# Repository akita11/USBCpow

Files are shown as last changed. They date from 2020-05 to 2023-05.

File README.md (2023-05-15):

# USBCpow

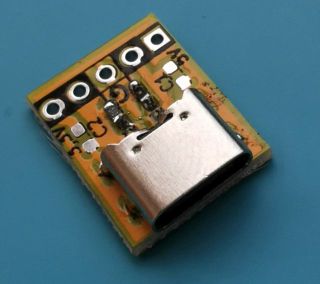
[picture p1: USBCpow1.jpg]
5V


USB Type-Cから5Vを供給するボードです。オプションで3.3Vレギュレータを載せて、3.3Vも出力することができます。

なお実際に供給できる電流は、給電側（USB ACアダプタやモバイルバッテリ）の性能に依存します。また3.3V出力は600mAまでです。

完成品はスイッチサイエンス等で委託販売中です。[5V版](https://www.switch-science.com/products/6434) / [5V/3.3V版](https://www.switch-science.com/products/6435)

# 使い方

+5V（および+3.3V）、GNDの端子にビニール線やピンヘッダやソケットをとりつけ、回路に電源を供給します。

以下のようにGNDと+5V（または+3.3V）に2ピンのピンヘッダをとりつけることで、ブレッドボードの電源ラインへの給電につかうことができます。

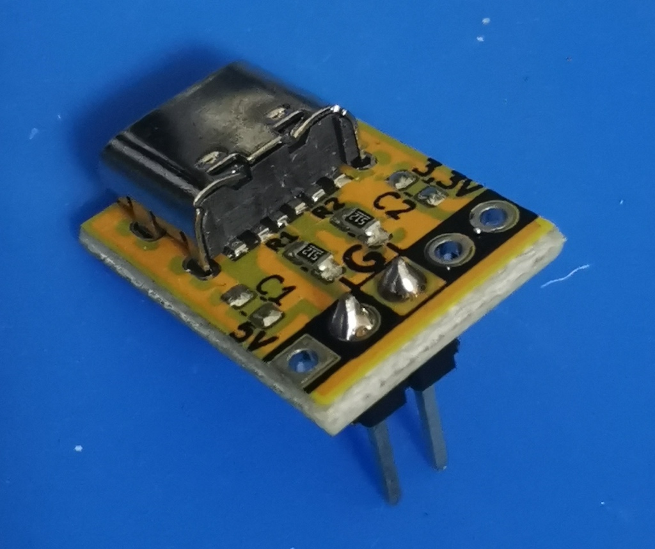
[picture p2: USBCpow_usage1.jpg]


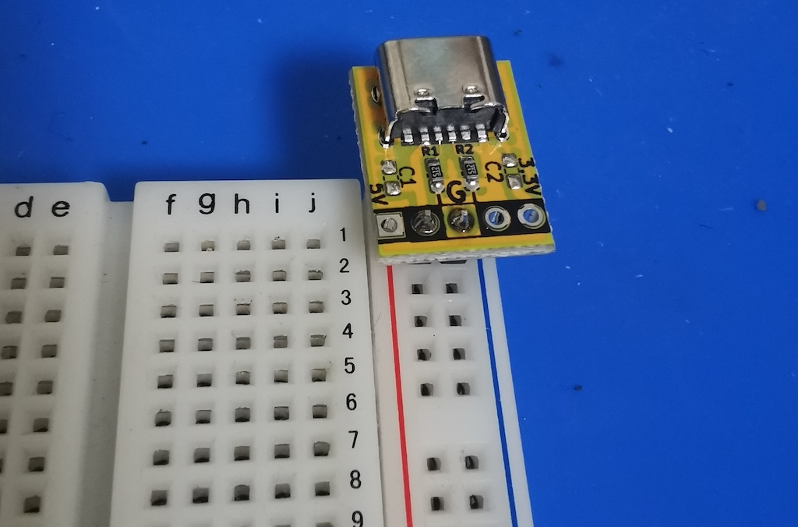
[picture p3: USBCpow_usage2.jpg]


以下のようにUSBコネクタ脇の穴に1ピンのピンヘッダをとりつけることで、ブレッドボードにしっかり固定することができます。

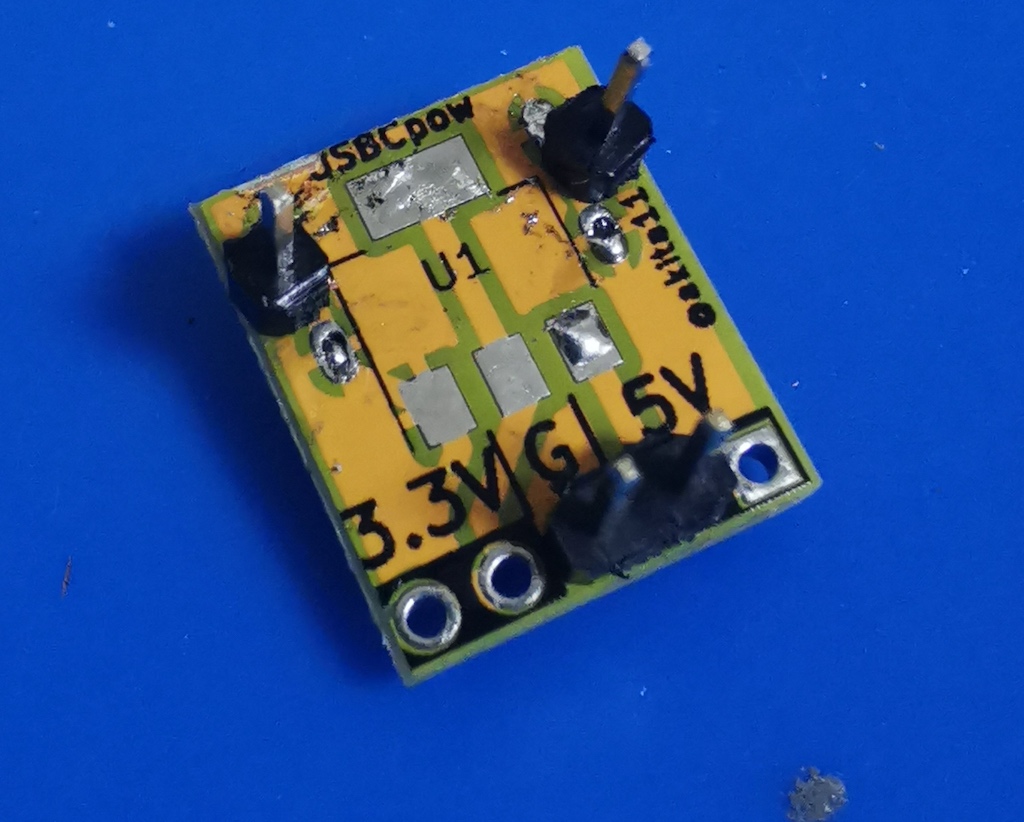
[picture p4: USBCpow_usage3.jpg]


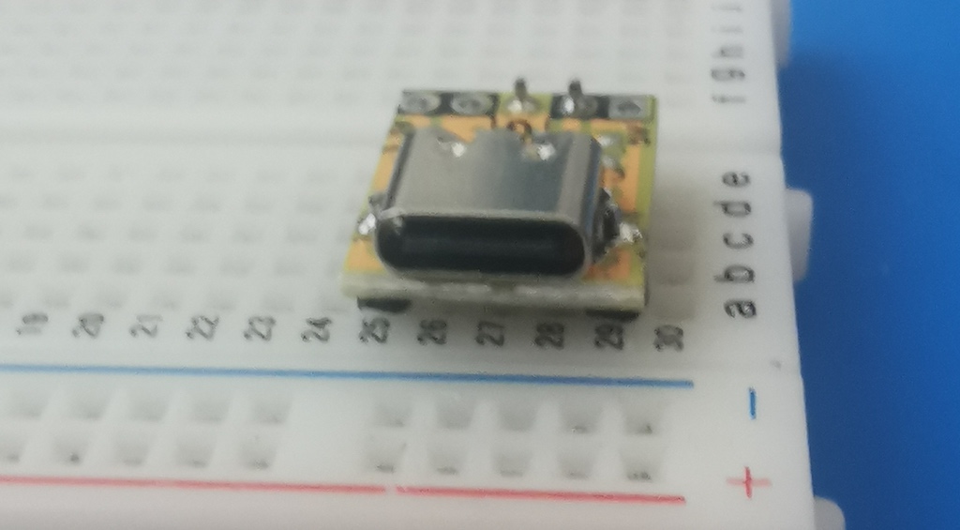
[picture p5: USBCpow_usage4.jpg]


# 作り方・必要部品

- [USB Type-Cコネクタ(6極)](https://www.aitendo.com/product/17279) 1個
- [チップ抵抗 5.1kΩ(1608サイズ)](https://www.aitendo.com/product/9962) 2個 ※R1,R2のところに実装
- 用途にあわせて、[ピンヘッダ5p](https://www.aitendo.com/product/1798)（出力部に取り付ける場合のみ）など

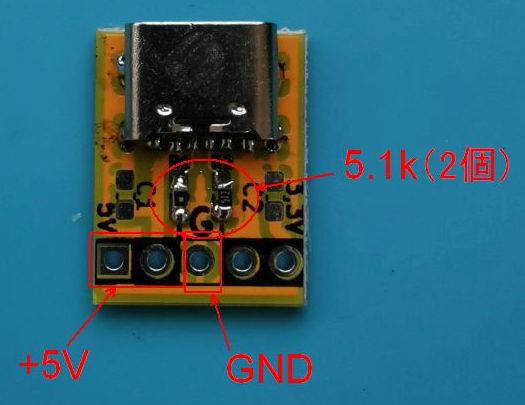
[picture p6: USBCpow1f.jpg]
5Vfunc


以下、3.3V出力を作る場合の追加部品
- [レギュレータLM1117-3.3（または互換品）](https://www.aitendo.com/product/13388) 1個
- [チップコンデンサ 10uF(1608サイズ)/10V以上](https://www.aitendo.com/product/6985) 2個 ※C1,C2のところに実装

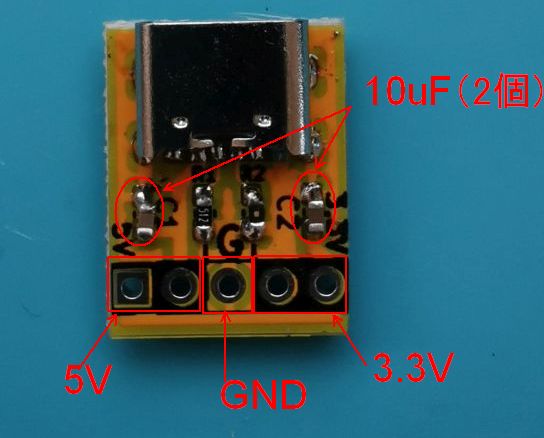
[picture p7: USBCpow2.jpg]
3.3V


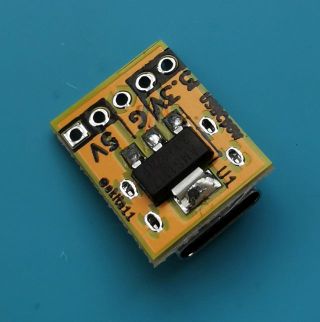
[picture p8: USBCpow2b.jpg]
3.3Vback


# Author

Junichi Akita (akita@ifdl.jp, @akita11)

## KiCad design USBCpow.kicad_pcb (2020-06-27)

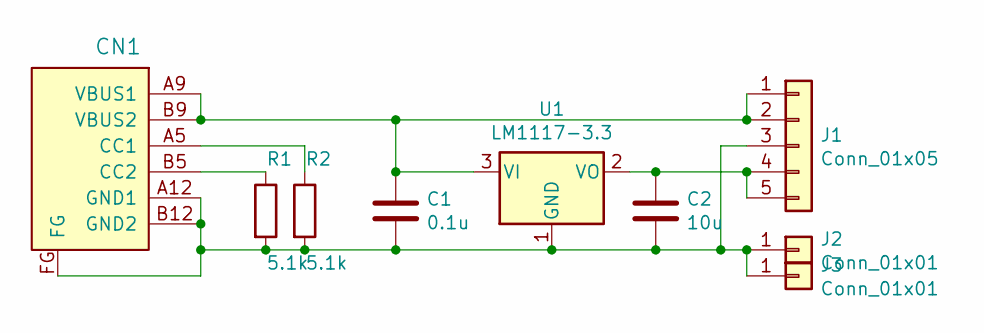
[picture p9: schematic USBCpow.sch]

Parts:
C1: 0.1u; C_0603_1608Metric_Pad1.05x0.95mm_HandSolder
C2: 10u; C_0603_1608Metric_Pad1.05x0.95mm_HandSolder
CN1: CON_USB-C-6; USB-C_6P
J1: Conn_01x05; PinHeader_1x05_P2.54mm_Vertical
J2, J3: Conn_01x01; PinHeader_1x01_P2.54mm_Vertical
R1, R2: 5.1k; R_0603_1608Metric_Pad1.05x0.95mm_HandSolder
U1: LM1117-3.3; SOT-223-3_TabPin2

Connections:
unnamed: C1.1, CN1.A9 (VBUS1), CN1.B9 (VBUS2), J1.1, J1.2, U1.3 (VI)
unnamed: C1.2, C2.2, CN1.A12 (GND1), CN1.B12 (GND2), CN1.FG, J1.3, J2.1, J3.1, R1.2, R2.2, U1.1 (GND)
unnamed: C2.1, J1.4, J1.5, U1.2 (VO)
unnamed: CN1.A5 (CC1), R2.1
unnamed: CN1.B5 (CC2), R1.1

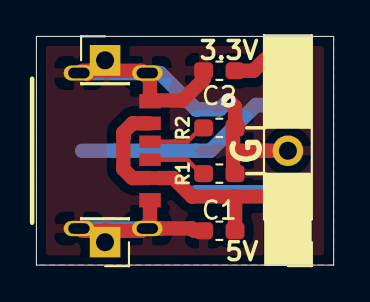
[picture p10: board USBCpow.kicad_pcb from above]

Board: 2 copper layers, 16.5 x 12.7 mm, 9 parts (1 on the bottom side), 5 nets.

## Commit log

2020-05-28 写真の追加
2020-05-28 写真サイズの変更
2020-06-14 USBコネクタのTHもペーストを追加＆発注用BOMの追加
    [USBCpow5x6.kicad_pcb, USBCpow5x6.xlsx]
2020-06-18 READMEに出力電流について追記
    [USBCpow5x6_bom.xlsx]
2020-06-27 固定用ピンヘッダの穴を追加
    [USBCpow.kicad_pcb, USBCpow.sch, USBCpow5x6.kicad_pcb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]
2023-05-15 add usage
    [USBCpow5x6.kicad_pcb, USBCpow5x6_bom.xlsx]
